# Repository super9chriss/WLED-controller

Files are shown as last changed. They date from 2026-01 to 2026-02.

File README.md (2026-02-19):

# WLED controller
A ESP32 C3 based microcontroller which is made to be used with WLED to use 12V or 24V ledsttrips.
I made this project since i want to add some lighting to my wall since its very dark, i wanted to learn something from this project so i made it into a devboard instead of a simpeler PCB design.
You can attach a 12 or 24V power supply to the Vin port which will directly power the ledstrip so this needs to have the same voltage rating and you can then use the ESP32 to adress the ledstrip.
<div align="center">


</div>

## Features

* **Microcontroller:** ESP32-C3-WROOM-02 with Wi-Fi and Bluetooth LE.
* **Power Input:** Supports 12V or 24V DC via dedicated screw terminals.
* **Logic Level Shifter:** Integrated SN74AHCT125DR to convert 3.3V logic to 5V for reliable LED data.
* **Connectivity:** USB-C receptacle for easy firmware flashing.
* **Led strip ports:** GPIO 1,3,4 and 5 are on the right side of the board(from bottom to top so top is 5 and bottom is 1) and can be used for ledstrips.
## How to use

1. Order the PCBA and lightstrip + powersupply.
2. Install WLED to the esp using https://install.wled.me/ if it doesnt work follow the steps on the website to install some drivers.
3. Configure WLED first connect the esp to wifi so you can remotly control the ledstrips, then add in the hardware setup which leds you are using, how many leds u use and on which pin the leds are connected(GPIO 1,3,4 and/or 5).


4. Disconnect the esp from your computer, and only then power it using the power supply also connect the ledstrip if you havent done this yet, and enjoy using the WLED controller.

## PCB and schematic
| **PCB Layout** | **Schematic** |
| :---: | :---: |
| |  |
||
||

## Wiring diagram


## BOM
|Component |price|link |
|---|-----|---|
|ledstrip + powersuply|21.79|https://nl.aliexpress.com/item/1005007038025239.html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|
|PCB |41.46|https://cart.jlcpcb.com/smt-order/?pcbFileNo=4c66db31f77f4dcd8bb62a3aeb8100a0 |

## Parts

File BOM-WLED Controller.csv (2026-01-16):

Component | price | link
ledstrip + powersuply | 21.79 | https://nl.aliexpress.com/item/1005007038025239.html?mp=1
PCB | 41.46 | https://cart.jlcpcb.com/smt-order/?pcbFileNo=4c66db31f77f4dcd8bb62a3aeb8100a0

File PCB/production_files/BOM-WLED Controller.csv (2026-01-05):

Comment | Designator | Footprint | LCSC | Quantity
0.1uF | C6,C8,C9 | C_0402_1005Metric | C307331 | 3
100nF | C11,C3 | C_0402_1005Metric | C307331 | 2
10k | R4,R6,R7,R8 | R_0402_1005Metric | C25744 | 4
10uF | C10,C7 | C_0603_1608Metric | C13585 | 2
1K | R3 | R_0402_1005Metric | C11702 | 1
22uF | C1,C12,C13,C2 | C_0603_1608Metric | C59461 | 4
3V3 | J9 | TerminalBlock_MaiXu_MX126-5.0-02P_1x02_P5.00mm | C1509679 | 1
4.7uH | L1 | L_Bourns-SRN8040_8x8.15mm | C36417 | 1
5.1K | R1,R2 | R_0402_1005Metric | C25905 | 2
500SSP1S2M2QEA | S1 | SW_500SSP1S2M2QEA | C92655 | 1
AP63205WU | U1 | TSOT-23-6 | C2071056 | 1
AP7361C-33E | U3 | SOT-223-3_TabPin2 | C500795 | 1
ESP32-C3-WROOM-02 | U2 | ESP32-C3-WROOM-02 | C2944070 | 1
PWRLED | D1 | LED_0603_1608Metric | C2286 | 1
SK6812 | D2 | LED_SK6812MINI_PLCC4_3.5x3.5mm_P1.75mm | C2886570 | 1
SN74AHCT125DR | U4 | SOIC127P600X175-14N | C155176 | 1
SW_Push | SW1,SW2 | SW_PUSH_6mm | C111374 | 2
Screw_Terminal_01x04 | J2 | TerminalBlock_MaiXu_MX126-5.0-04P_1x04_P5.00mm | C1509680 | 1
Screw_Terminal_01x12 | J3 | TerminalBlock_MaiXu_MX126-5.0-12P_1x12_P5.00mm | C1509686 | 1
USB_C_Receptacle_USB2.0_14P | J1 | USB_C_Receptacle_HRO_TYPE-C-31-M-12 | C165948 | 1
Vin | J6 | TerminalBlock_MaiXu_MX126-5.0-02P_1x02_P5.00mm | C1509679 | 1

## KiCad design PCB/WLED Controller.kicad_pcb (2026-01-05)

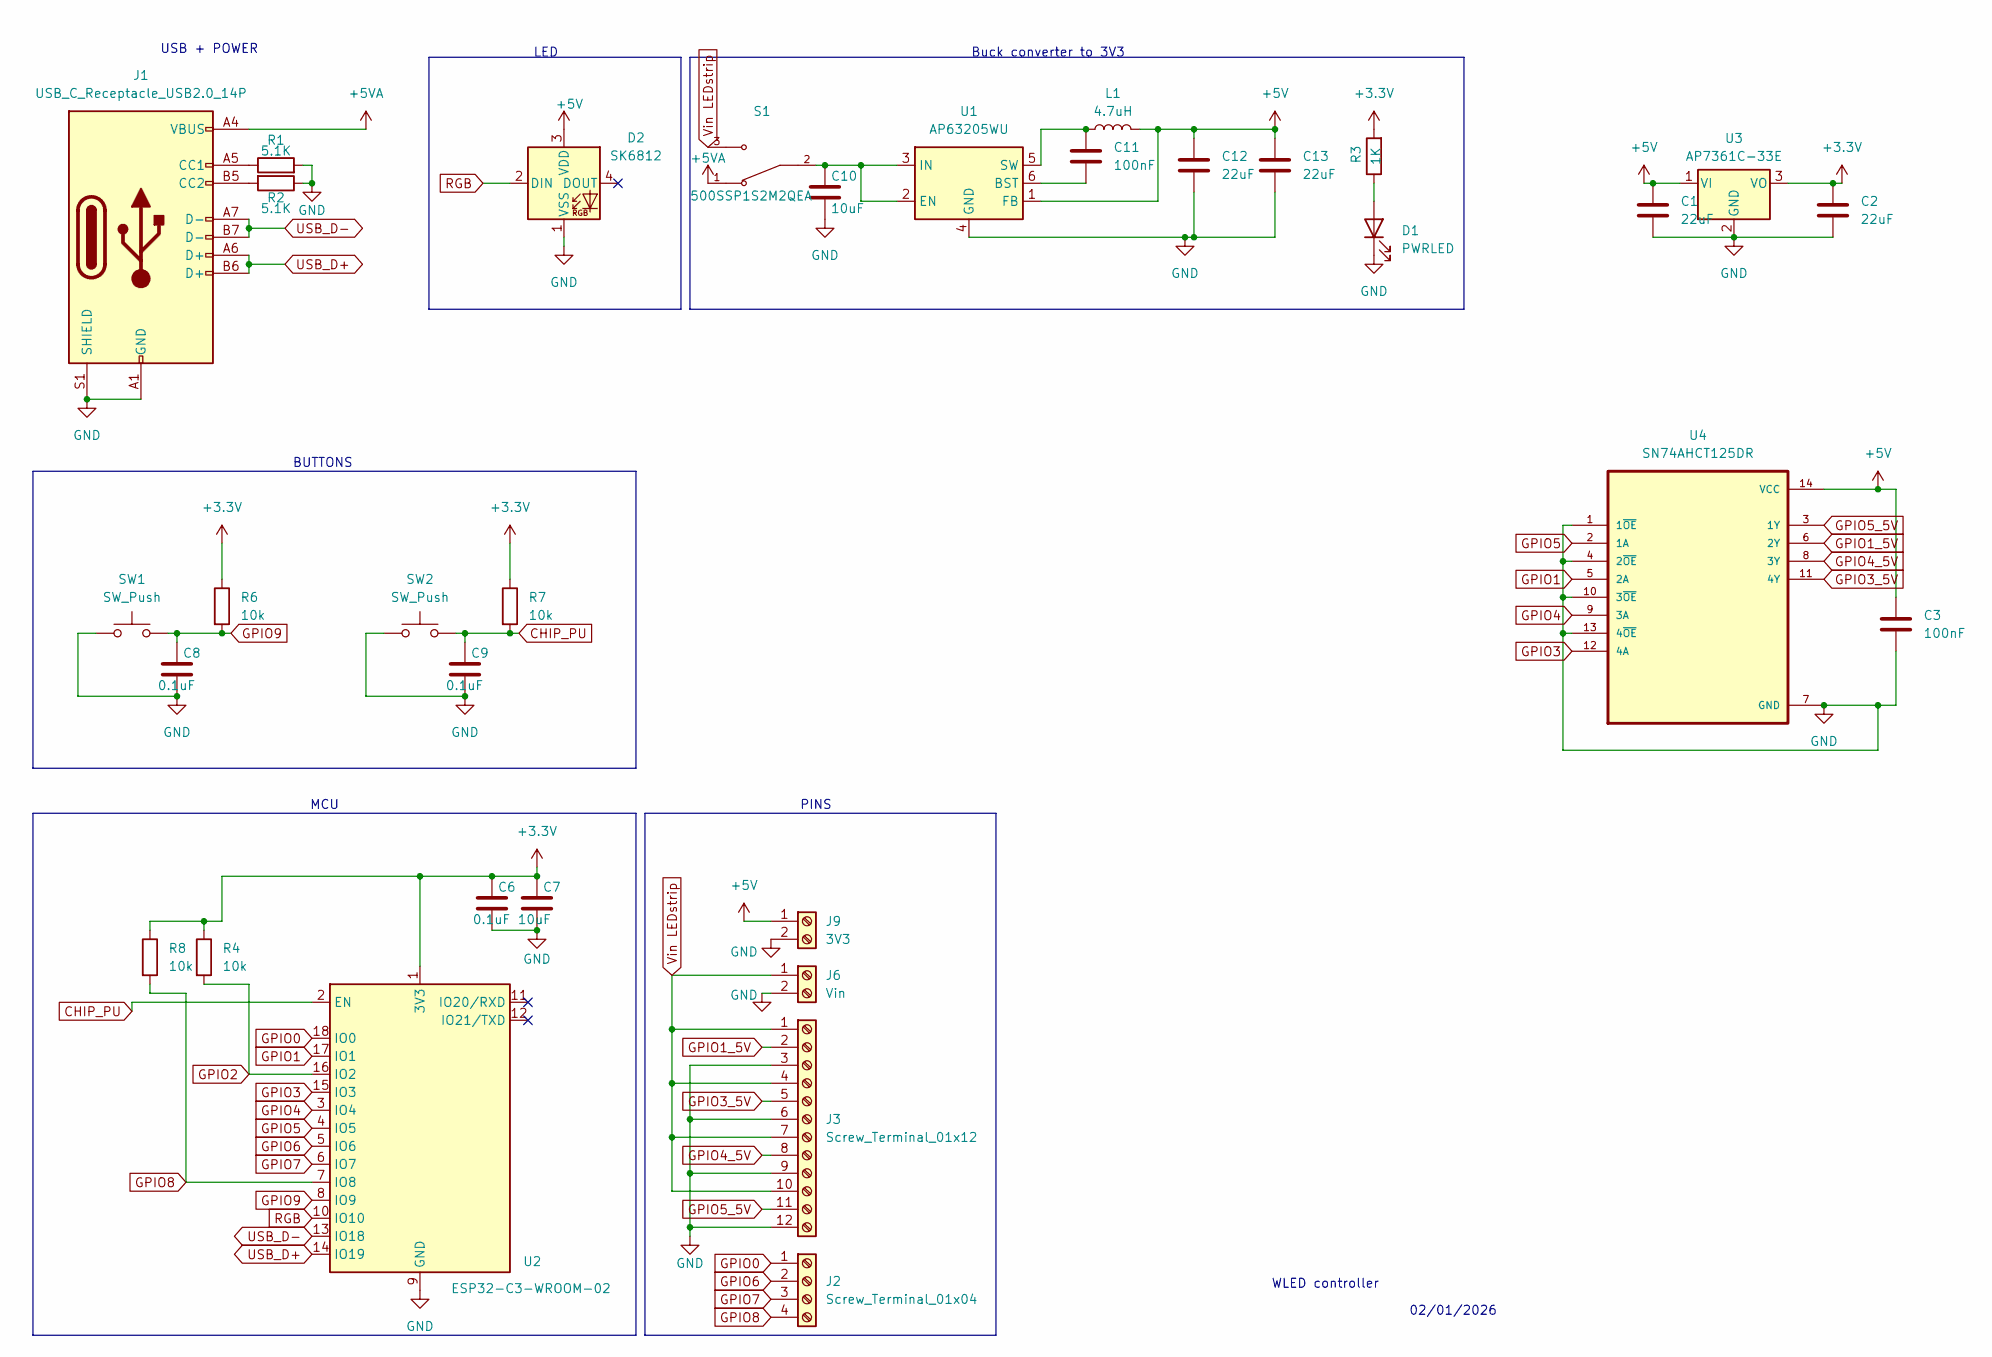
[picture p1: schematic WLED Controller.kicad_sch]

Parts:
C1, C2, C12, C13: 22uF; C_0603_1608Metric
C3, C11: 100nF; C_0402_1005Metric
C6, C8, C9: 0.1uF; C_0402_1005Metric
C7: 10uF; C_1206_3216Metric
C10: 10uF; C_0603_1608Metric
D1: PWRLED; LED_0603_1608Metric
D2: SK6812; LED_SK6812MINI_PLCC4_3.5x3.5mm_P1.75mm
J1: USB_C_Receptacle_USB2.0_14P; USB_C_Receptacle_HRO_TYPE-C-31-M-12
J2: Screw_Terminal_01x04; TerminalBlock_MaiXu_MX126-5.0-04P_1x04_P5.00mm
J3: Screw_Terminal_01x12; TerminalBlock_MaiXu_MX126-5.0-12P_1x12_P5.00mm
J6: Vin; TerminalBlock_MaiXu_MX126-5.0-02P_1x02_P5.00mm
J9: 3V3; TerminalBlock_MaiXu_MX126-5.0-02P_1x02_P5.00mm
L1: 4.7uH; L_Bourns-SRN8040_8x8.15mm
R1, R2: 5.1K; R_0402_1005Metric
R3: 1K; R_0402_1005Metric
R4, R6, R7, R8: 10k; R_0402_1005Metric
S1: 500SSP1S2M2QEA; SW_500SSP1S2M2QEA; PARTREV C
SW1, SW2: SW_Push; SW_PUSH_6mm
U1: AP63205WU; TSOT-23-6
U2: ESP32-C3-WROOM-02
U3: AP7361C-33E; SOT-223-3_TabPin2
U4: SN74AHCT125DR; SOIC127P600X175-14N

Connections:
+3.3V: C2.1, C6.1, C7.1, R3.2, R4.1, R6.1, R7.1, R8.1, U2.1 (3V3), U3.3 (VO)
+5V: C1.1, C3.1, C12.1, C13.1, D2.3 (VDD), J9.1, L1.2, U1.1 (FB), U3.1 (VI), U4.14 (VCC)
+5VA: J1.A4 (VBUS), J1.A9 (VBUS), J1.B4 (VBUS), J1.B9 (VBUS), S1.1
CHIP_PU: C9.1, R7.2, SW2.2, U2.2 (EN)
GND: C1.2, C2.2, C3.2, C6.2, C7.2, C8.2, C9.2, C10.2, C12.2, C13.2, D1.1 (K), D2.1 (VSS), J1.A1 (GND), J1.A12 (GND), J1.B1 (GND), J1.B12 (GND), J1.S1 (SHIELD), J3.3, J3.6, J3.9, J3.12, J6.2, J9.2, R1.2, R2.1, SW1.1, SW2.1, U1.4 (GND), U2.9 (GND), U2.19 (GND), U3.2 (GND), U4.1 (1~OE), U4.4 (2~OE), U4.7 (GND), U4.10 (3~OE), U4.13 (4~OE)
GPIO0: J2.1, U2.18 (IO0)
GPIO1: U2.17 (IO1), U4.5 (2A)
GPIO1_5V: J3.2, U4.6 (2Y)
GPIO2: R4.2, U2.16 (IO2)
GPIO3: U2.15 (IO3), U4.12 (4A)
GPIO3_5V: J3.5, U4.11 (4Y)
GPIO4: U2.3 (IO4), U4.9 (3A)
GPIO4_5V: J3.8, U4.8 (3Y)
GPIO5: U2.4 (IO5), U4.2 (1A)
GPIO5_5V: J3.11, U4.3 (1Y)
GPIO6: J2.2, U2.5 (IO6)
GPIO7: J2.3, U2.6 (IO7)
GPIO8: J2.4, R8.2, U2.7 (IO8)
GPIO9: C8.1, R6.2, SW1.2, U2.8 (IO9)
unnamed: D1.2 (A), R3.1
unnamed: J1.A5 (CC1), R1.1
unnamed: J1.B5 (CC2), R2.2
unnamed: C11.2, U1.6 (BST)
unnamed: C10.1, S1.2, U1.2 (EN), U1.3 (IN)
unnamed: C11.1, L1.1, U1.5 (SW)
RGB: D2.2 (DIN), U2.10 (IO10)
USB_D+: J1.A6 (D+), J1.B6 (D+), U2.14 (IO19)
USB_D-: J1.A7 (D-), J1.B7 (D-), U2.13 (IO18)
Vin LEDstrip: J3.1, J3.4, J3.7, J3.10, J6.1, S1.3

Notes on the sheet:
PINS
USB + POWER
02/01/2026
BUTTONS
LED
Buck converter to 3V3
MCU
WLED controller

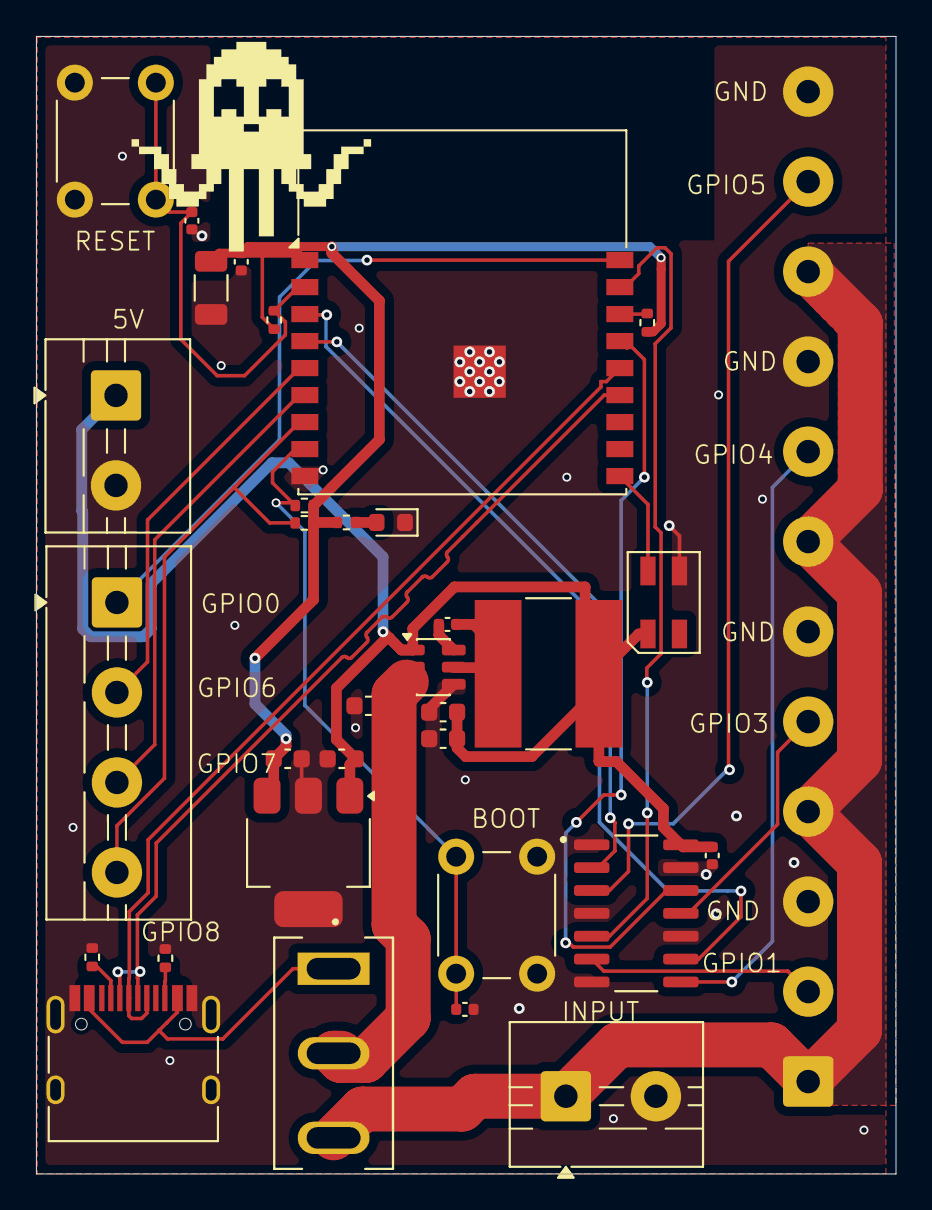
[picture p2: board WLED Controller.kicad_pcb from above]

Board: 2 copper layers, 47.8 x 63.2 mm, 33 parts (0 on the bottom side), 29 nets.
